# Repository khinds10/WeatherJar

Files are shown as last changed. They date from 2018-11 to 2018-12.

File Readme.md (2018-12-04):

# WeatherCandle - Weather and Temperature at a glance
Using this magic candle, you can tell the current temperature and conditions outside instantly

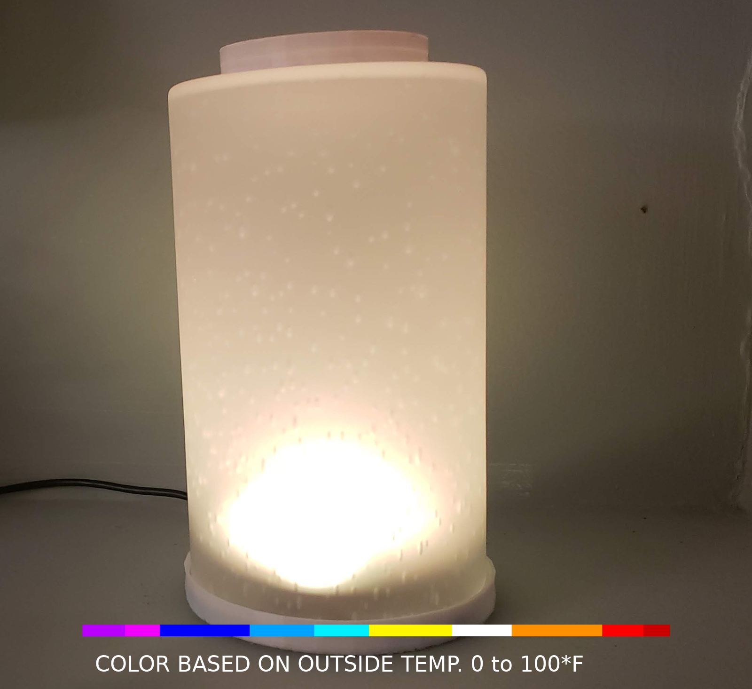
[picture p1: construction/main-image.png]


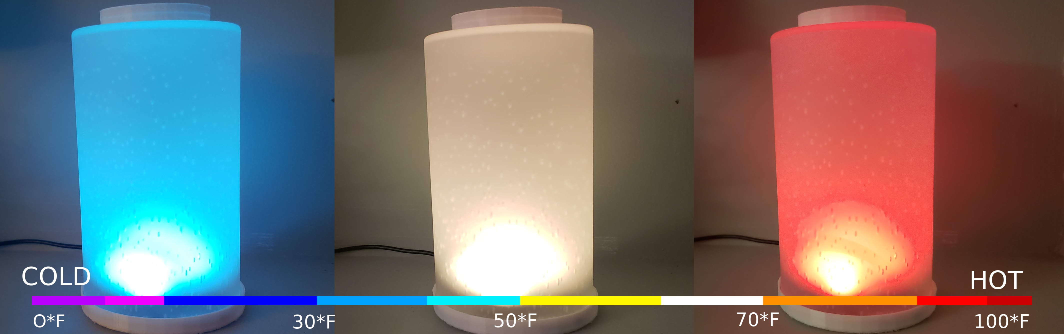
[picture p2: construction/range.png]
Color Range 0 to 100*F


**Color Range 0 to 100*F**

### Animations in Action

### IMAGE ALT TEXT (https://www.youtube.com/watch?v=RNsYiCd4rvg "Weather Candle")

#### Flashing RaspberriPi Hard Disk / Install Required Software (Using Ubuntu Linux)

Download "RASPBIAN JESSIE LITE"
https://www.raspberrypi.org/downloads/raspbian/

**Create your new hard disk for DashboardPI**
>Insert the microSD to your computer via USB adapter and create the disk image using the `dd` command
>
> Locate your inserted microSD card via the `df -h` command, unmount it and create the disk image with the disk copy `dd` command
>
> $ `df -h`
> */dev/sdb1       7.4G   32K  7.4G   1% /media/XXX/1234-5678*
>
> $ `umount /dev/sdb1`
>
> **Caution: be sure the command is completely accurate, you can damage other disks with this command**
>
> *if=location of RASPBIAN JESSIE LITE image file*
> *of=location of your microSD card*
>
> $ `sudo dd bs=4M if=/path/to/raspbian-jessie-lite.img of=/dev/sdb`
> *(note: in this case, it's /dev/sdb, /dev/sdb1 was an existing factory partition on the microSD)*

**Setting up your RaspberriPi**

*Insert your new microSD card to the raspberrypi and power it on with a monitor connected to the HDMI port*

Login
> user: **pi**
> pass: **raspberry**

Change your account password for security
>`sudo passwd pi`

Enable RaspberriPi Advanced Options
>`sudo raspi-config`

Choose:
`1 Expand File System`

`9 Advanced Options`
>`A2 Hostname`
>*change it to "WeatherJar"*
>
>`A4 SSH`
>*Enable SSH Server*
>
>`A7 I2C`
>*Enable i2c interface*

**Enable the English/US Keyboard**

>`sudo nano /etc/default/keyboard`

> Change the following line:
>`XKBLAYOUT="us"`

**Reboot PI for Keyboard layout changes / file system resizing to take effect**
>$ `sudo shutdown -r now`

**Auto-Connect to your WiFi**

>`sudo nano /etc/wpa_supplicant/wpa_supplicant.conf`

Add the following lines to have your raspberrypi automatically connect to your home WiFi
*(if your wireless network is named "linksys" for example, in the following example)*

	network={
	   ssid="linksys"
	   psk="WIRELESS PASSWORD HERE"
	}

**Reboot PI to connect to WiFi network**

>$ `sudo shutdown -r now`
>
>Now that your PI is finally on the local network, you can login remotely to it via SSH.
>But first you need to get the IP address it currently has.
>
>$ `ifconfig`
>*Look for "inet addr: 192.168.XXX.XXX" in the following command's output for your PI's IP Address*

**Go to another machine and login to your raspberrypi via ssh**

> $ `ssh pi@192.168.XXX.XXX`

**Start Installing required packages**

>$ `sudo apt-get update`
>
>$ `sudo apt-get upgrade`
>
>$ `sudo apt-get install memcached vim git python-smbus i2c-tools python-imaging python-smbus build-essential python-dev rpi.gpio python3 python3-pip python-memcache`

**Update local timezone settings

>$ `sudo dpkg-reconfigure tzdata`

`select your timezone using the interface`

**Setup the simple directory `l` command [optional]**

>`vi ~/.bashrc`
>
>*add the following line:*
>
>`alias l='ls -lh'`
>
>`source ~/.bashrc`

**Fix VIM default syntax highlighting [optional]**

>`sudo vi  /etc/vim/vimrc`
>
>uncomment the following line:
>
>_syntax on_

**Install i2c Python Drivers**

Install the NeoPixel Driver as follows 

>`sudo apt-get install build-essential python-dev git scons swig`
>
>`sudo pip3 install --upgrade setuptools`
>
>`sudo pip3 install rpi_ws281x`
>
>`cd rpi_ws281x`
>
>`scons`
>
>`cd python`
>
>`sudo python setup.py install`
>
>`cd examples/`
>
>`sudo python strandtest.py`

# Supplies Needed

**RaspberryPi Zero**

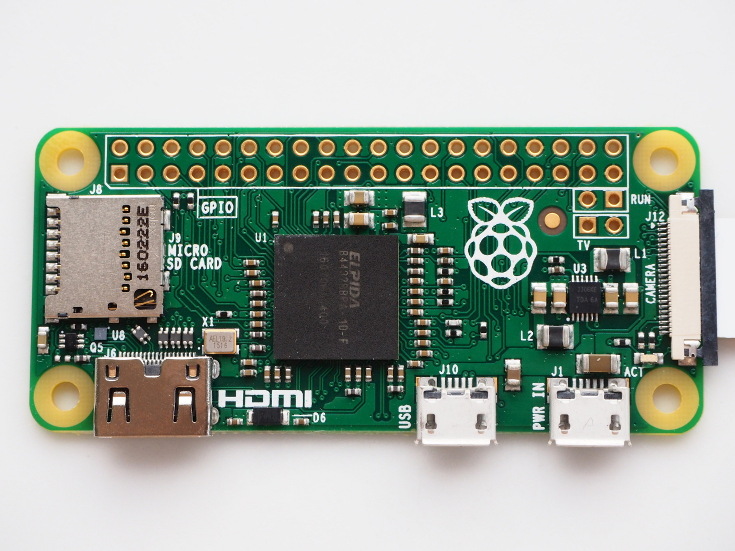
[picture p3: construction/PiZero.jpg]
RaspberryPi Zero


**USB WIFI (if not a PiZero W)**

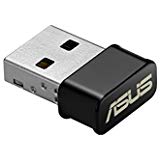
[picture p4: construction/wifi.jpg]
USB WIFI (if not a PiZero W)


**NeoPixel Ring**

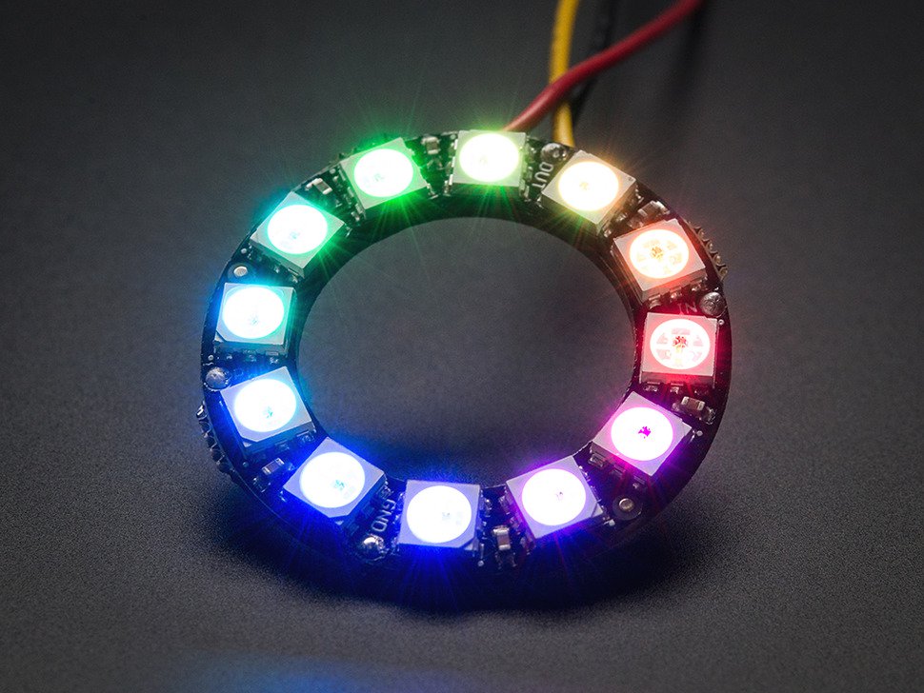
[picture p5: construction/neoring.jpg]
NeoPixel Ring


**Frosted Lamp Shade**

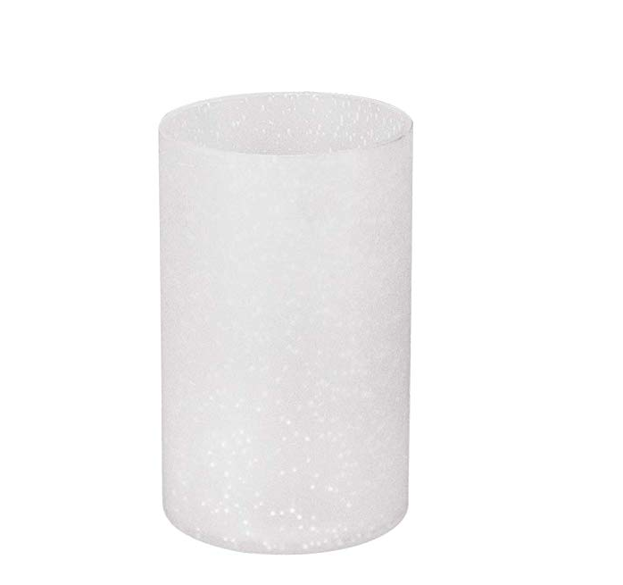
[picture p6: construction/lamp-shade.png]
Frosted Lamp Shade


# Building the WeatherJar

Solder the leads to connect the NeoPixel Ring to the Pi, needs 5V, GND and GPIO pin 18 connected

*Note: since we're only using one ring with not ever showing full brightness / bright white colors, we can rely on the power source of the RPi itself.  Ordinarily they recommend the 5050 RGB pixesl such as these to have their own power source.

### Wiring the Components

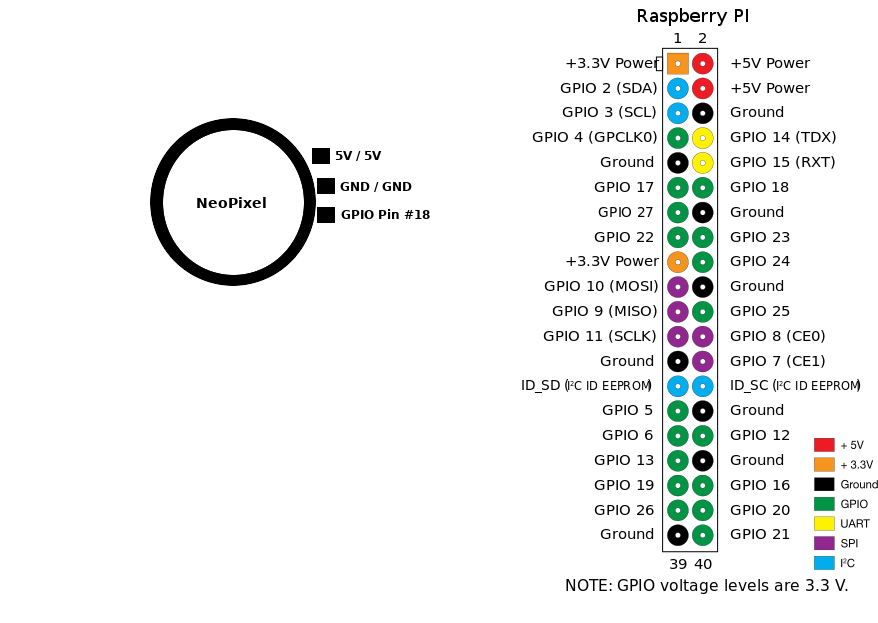
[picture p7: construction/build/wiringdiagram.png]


Connect the NeoPixel to 5v and GND on the RPi, connect the "in" pin on the NeoPixel ring to GPIO Pin #18

## Print the Enclosure

In the 3D-Print/ folder of this project, print the lid and the base of the candle to contain the device.

## Build the Candle

Using a hot glue gun, glue the pi zero to the bottom of the candle base

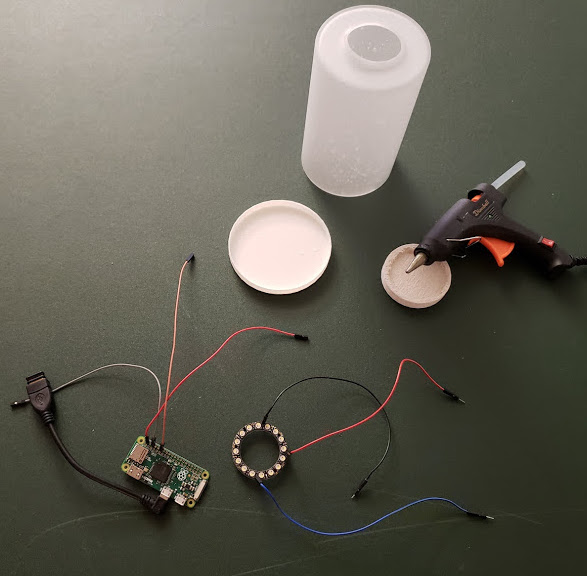
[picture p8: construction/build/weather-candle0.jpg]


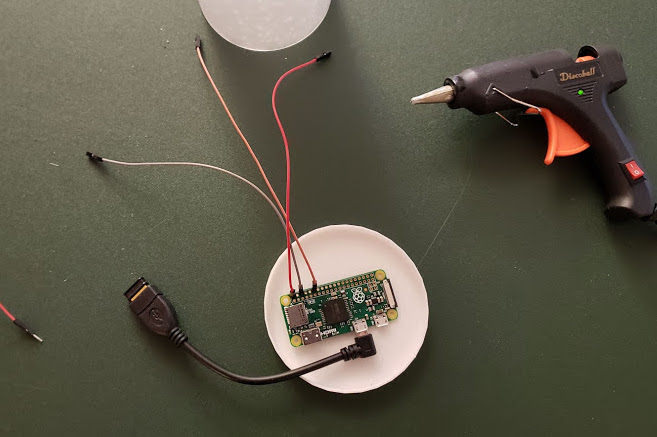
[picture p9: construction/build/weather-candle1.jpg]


Drill a hole to allow for the power USB cable to come in

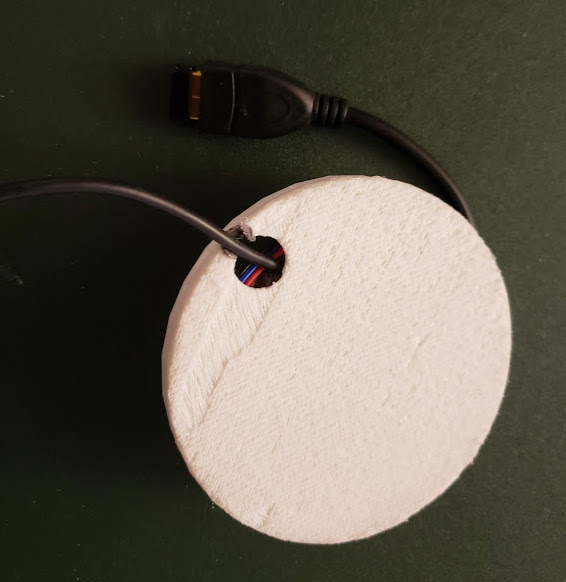
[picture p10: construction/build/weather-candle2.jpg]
Wire Power


I've used some simple tape to hold the NeoPixel Ring to the button of the candle, tucking the wires away to ensure the light is blocked by any strange shadows inside.

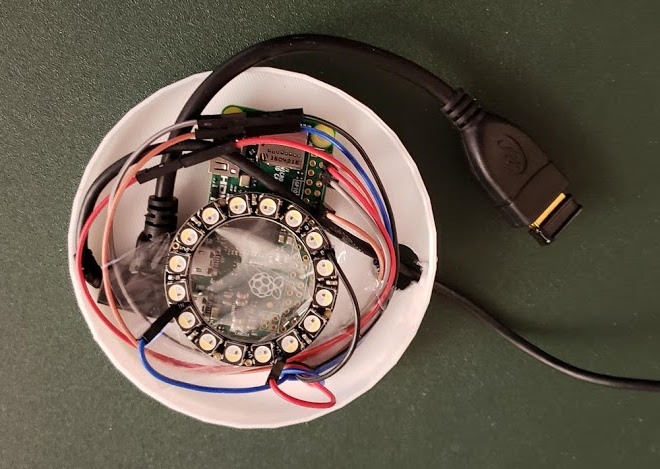
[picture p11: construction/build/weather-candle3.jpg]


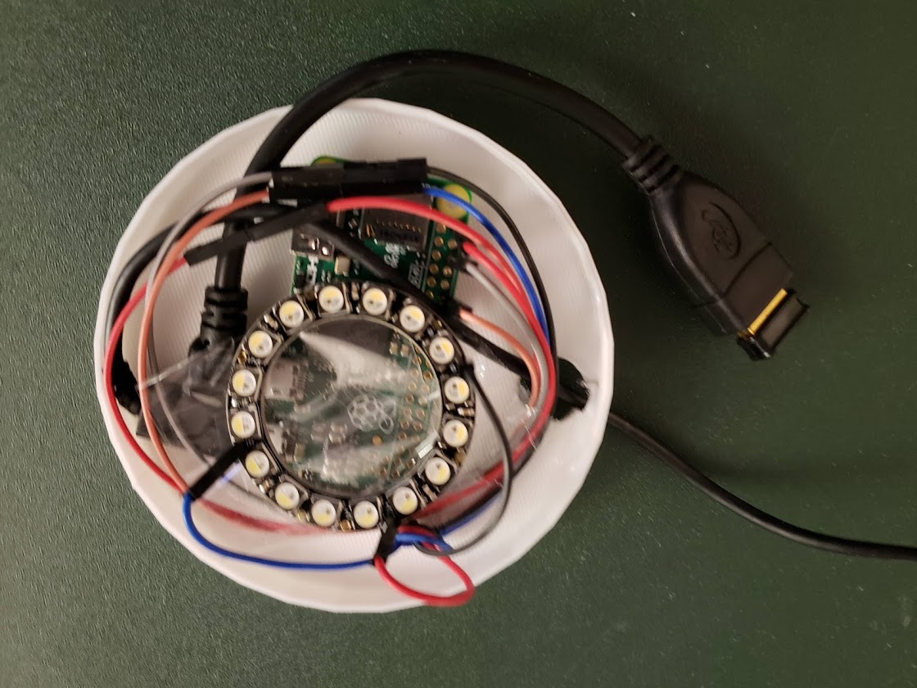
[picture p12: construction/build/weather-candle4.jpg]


# Creating the Temperature API

Python Flash API for displaying temperatures as color gradients installation instructions

### Installation

Clone the project webserver folder locally on your webserver from this project [/var/www]

Create the Apache configuration to point to this project (Python Flask API)

Required Packages for Python Flash on Apache

`$> sudo apt-get install libapache2-mod-wsgi python-dev python-pip python-pil`

`$> sudo a2enmod wsgi`

`$> sudo service apache2 restart`

`$> pip install flask`

    <VirtualHost *:80>
        ServerAdmin webmaster@mytempuratureapi.com
        ServerName mytempuratureapi.com
        ServerAlias mytempuratureapi.com
        DocumentRoot /var/www/temperatureapi
        ErrorLog /var/www/temperatureapi/error.log
        CustomLog /var/www/temperatureapi/access.log combined
    
        WSGIDaemonProcess temperatureapp user=khinds group=khinds threads=5
        WSGIProcessGroup temperatureapp
        WSGIScriptAlias / /var/www/temperatureapi/app.wsgi
    
        <Directory /var/www/temperatureapi>
               Require all granted
        </Directory>
    
    </VirtualHost>

You can now ask for RGB NeoPixel color gradients for given environment temperatures

http://mytempuratureapi.com/neopixel?temperature=72

### Set pi user crontab 

Enter the following line for a minute by minute crontab

`$ crontab -e`

`*/1 * * * * python /home/pi/WeatherJar/weather.py`

### Set root user crontab (this library requires root access)

Set "on reboot" to run the candle python script forever

`$ sudo su`

`$ crontab -e`

`@reboot python /home/pi/WeatherJar/candle.py`

**Color Range 0 to 100*F**

Color Range 0 to 100*FBe sure to place this new URL you generated in your project settings so you can now have the weather jar respond to your current outdoor temperatures.

# Finished!

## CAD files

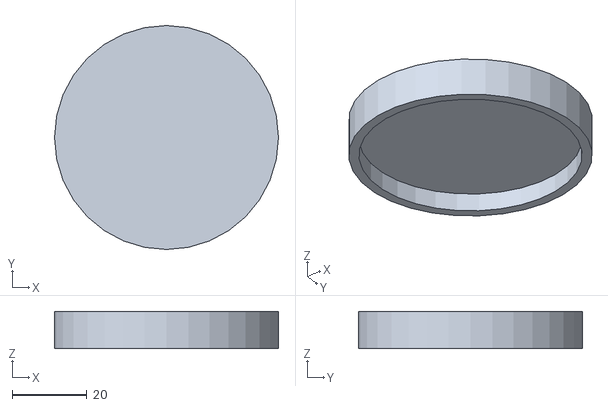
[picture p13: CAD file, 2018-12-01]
construction/3D-Print/lid.stl
60.0 x 60.0 x 10.0

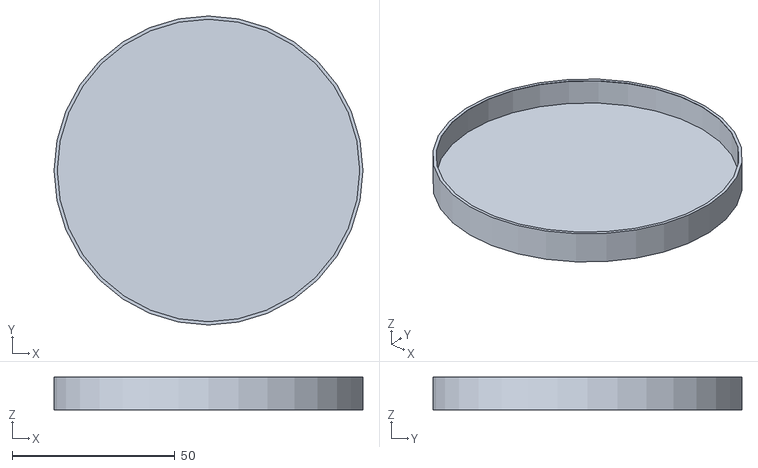
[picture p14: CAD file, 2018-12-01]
construction/3D-Print/base.stl
95.0 x 95.0 x 10.0

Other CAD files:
construction/3D-Print/print.blend

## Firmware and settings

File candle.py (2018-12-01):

#!/usr/bin/python
# Kevin Hinds http://www.kevinhinds.com
# License: GPL 2.0
import sys, time, json, string, cgi, subprocess, json, datetime, memcache
import settings as settings
from neopixel import *
from random import *
mc = memcache.Client(['127.0.0.1:11211'], debug=0)

# rain raindrops timeout length (generated randomly) 
rainDrops = ['0.1', '0.2', '0.3', '0.4', '0.8', '0.9']

# wind speed timeout length (generated randomly) 
windSpeed = ['0.02', '0.03', '0.04', '0.05', '0.06', '0.07', '0.08']

# LED strip configuration:import settings as settings
LED_COUNT      = 16     # Number of LED pixels.
LED_PIN        = 18      # GPIO pin connected to the pixels (18 uses PWM!).
LED_FREQ_HZ    = 800000  # LED signal frequency in hertz (usually 800khz)
LED_DMA        = 10      # DMA channel to use for generating signal (try 10)
LED_BRIGHTNESS = 255     # Set to 0 for darkest and 255 for brightest
LED_INVERT     = False   # True to invert the signal (when using NPN transistor level shift)
LED_CHANNEL    = 0       # set to '1' for GPIOs 13, 19, 41, 45 or 53

############################################
######## YOU HAVE TO RUN AS ROOT!
############################################

# setup the strip
strip = Adafruit_NeoPixel(LED_COUNT, LED_PIN, LED_FREQ_HZ, LED_DMA, LED_INVERT, LED_BRIGHTNESS, LED_CHANNEL, ws.WS2811_STRIP_GRB)
strip.begin()

# set all pixels to black
for i in range(0, strip.numPixels()):
    strip.setPixelColor(i, Color(0, 0, 0))
strip.show()

def hexToRGB(value):
    value = value.lstrip('#')
    lv = len(value)
    return tuple(int(value[i:i + lv // 3], 16) for i in range(0, lv, lv // 3))

def setEventPin(pin, brightness, speed):
    global strip
    strip.setPixelColor(pin, Color(brightness, brightness, brightness))
    strip.show()
    time.sleep(speed)

def turnOnOff(pin, brightness, speed):
    global strip
    setEventPin(pin, brightness, speed)
    setEventPin(pin, 0, speed)

def getDrop():
    """get random raindrop length for effect"""
    global rainDrops
    shuffle(rainDrops)
    return float(rainDrops[0])

def getGust():
    """get random wind gust length for effect"""
    global windSpeed
    shuffle(windSpeed)
    return float(windSpeed[0])

def rain(temperatureColor):
    """rain blinking effect"""    
    # make the effect more pronounced for when the candle is already white
    rainBrightness = 50
    if temperatureColor == "#ffffff":
        rainBrightness = 100
    turnOnOff(2, rainBrightness, getDrop())
    turnOnOff(3, rainBrightness, getDrop())
    turnOnOff(7, rainBrightness, getDrop())
    turnOnOff(11, rainBrightness, getDrop())
    
def wind(temperatureColor):
    """wind faster blinking effect"""
    # make the effect more pronounced for when the candle is already white
    windBrightness = 25
    if temperatureColor == "#ffffff":
        windBrightness = 50
    turnOnOff(2, windBrightness, getGust())
    turnOnOff(3, windBrightness, getGust())
    turnOnOff(7, windBrightness, getGust())
    turnOnOff(11, windBrightness, getGust())
    
def snow(temperatureColor):
    """snow fading effect"""
    count = 0
    while count < 255:
        count = count + 1
        setEventPin(11, count, 0.005)
    while count > 0:
        count = count - 1
        setEventPin(11, count, 0.005)

# run the candle infinitely, getting the current temp and conditions
while True:
    try:
        temperatureColor = mc.get("TEMPERATURE")
        rgbValue = hexToRGB(temperatureColor)
        for i in range(0, strip.numPixels(), 4):
            strip.setPixelColor(i, Color(rgbValue[0], rgbValue[1], rgbValue[2]))
        strip.show()
        conditions = mc.get("CONDITIONS")
        if conditions == "RAIN":
            rain(temperatureColor)
        if conditions == "WIND":
            wind(temperatureColor)
        if conditions == "SNOW":
            snow(temperatureColor)
    except (Exception):
        time.sleep(1)

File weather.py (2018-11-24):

#!/usr/bin/python
# Kevin Hinds http://www.kevinhinds.com
# License: GPL 2.0
import sys, time, json, string, cgi, subprocess, json, datetime, memcache
import settings as settings
mc = memcache.Client(['127.0.0.1:11211'], debug=0)

# get the temp and conditions for candle to reflect changes, sets to memcache for candle to read
count = 0
while count < 10:
    try:
        count = count + 1        
        weatherInfo = json.loads(subprocess.check_output(['curl', settings.weatherAPIURL ]))
        currentFeelsLikeTemp = weatherInfo['currently']['apparentTemperature']
        
        # get the color for the current temp and set the jar to glow in that color
        colorInfo = subprocess.check_output(['curl', settings.tempColorAPI + '/neopixel?temperature=' + str(int(currentFeelsLikeTemp))   ])
        mc.set("TEMPERATURE", str(colorInfo))
        mc.set("CONDITIONS", "NONE")
        if weatherInfo['currently']['precipProbability'] == 1:
            if weatherInfo['currently']['precipType'] == "snow":
                mc.set("CONDITIONS", "SNOW")    
            if weatherInfo['currently']['precipType'] == "rain":
                mc.set("CONDITIONS", "RAIN")
        else:
            if weatherInfo['currently']['windSpeed'] > 25:
                mc.set("CONDITIONS", "WIND")
        break
    except (Exception):
        time.sleep(10)

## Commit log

2018-11-23 switched to memcached solution with polling for any changes to weather for the long running candle.py script
2018-11-30 fix for contest submission
    [candle.py]
2018-12-01 added final construction and print images
    [base.stl, lid.stl, print.blend]
